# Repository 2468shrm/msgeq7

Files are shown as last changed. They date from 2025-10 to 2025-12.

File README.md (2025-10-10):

# msgeq7

A PCB to interface an MSGEQ7 seven channel graphic equalizer IC to my smart sensor platform [link](https://github.com/2468shrm/M4_CAN_Feather_Carrier_v6). The board has a microphone input jack, the MSGEQ7 IC, and three 3-position square pin headers. One header for RESET, one for STROBE, and one for the analog OUTPUT.  These are connected to two DIOs and an AIN, respectively.

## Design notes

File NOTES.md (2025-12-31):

# MSGEQ7 Project

## Requirements

- Audio input
  - Microphone input (3.5mm [1/8"] stereo jacks)
    - CUI SJ-3523-SMT (without switch)

- Connects to Smart Sensor Platform
  - 2 DIOs connect to STROBE and RESET and also provides 3.3V power
    - DIO power jumper
  - 1 AIN connects to DCOUT
- 3.3 V operation
  - 100 uF bulk cap
- MSGEQ7 PTH variant (from SparkFun)
  - Socketed

- Application on the mart Sensor Platform provides:
  - Bling output

- Sensor Platform
  - Battery powered

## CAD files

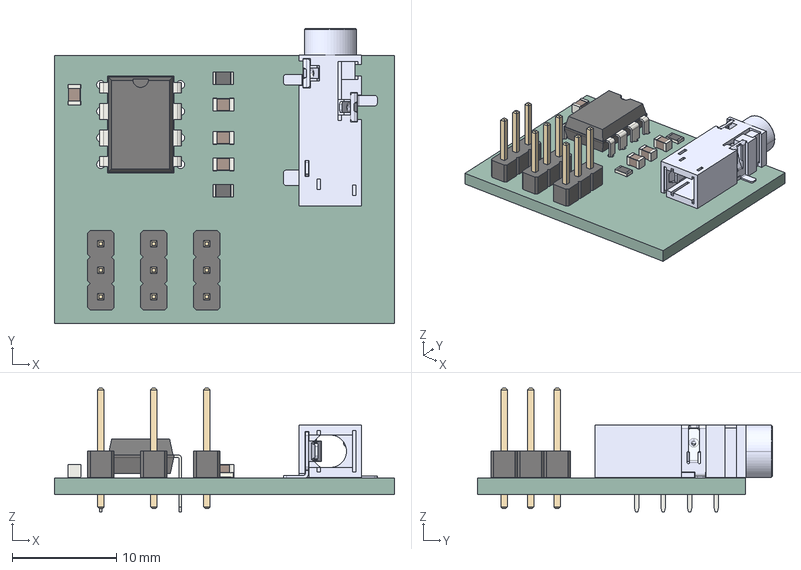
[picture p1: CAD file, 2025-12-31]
breakout/3D/breakout.step
32.6 x 28.2 x 11.8 mm
C_0805_2012Metric x 4
R_0805_2012Metric x 2
CUI_DEVICES_SJ-3523-SMT-TR
PinHeader_1x03_P254mm_Vertical x 3
DIP-8_W7.62mm
_autosave-breakout_PCB

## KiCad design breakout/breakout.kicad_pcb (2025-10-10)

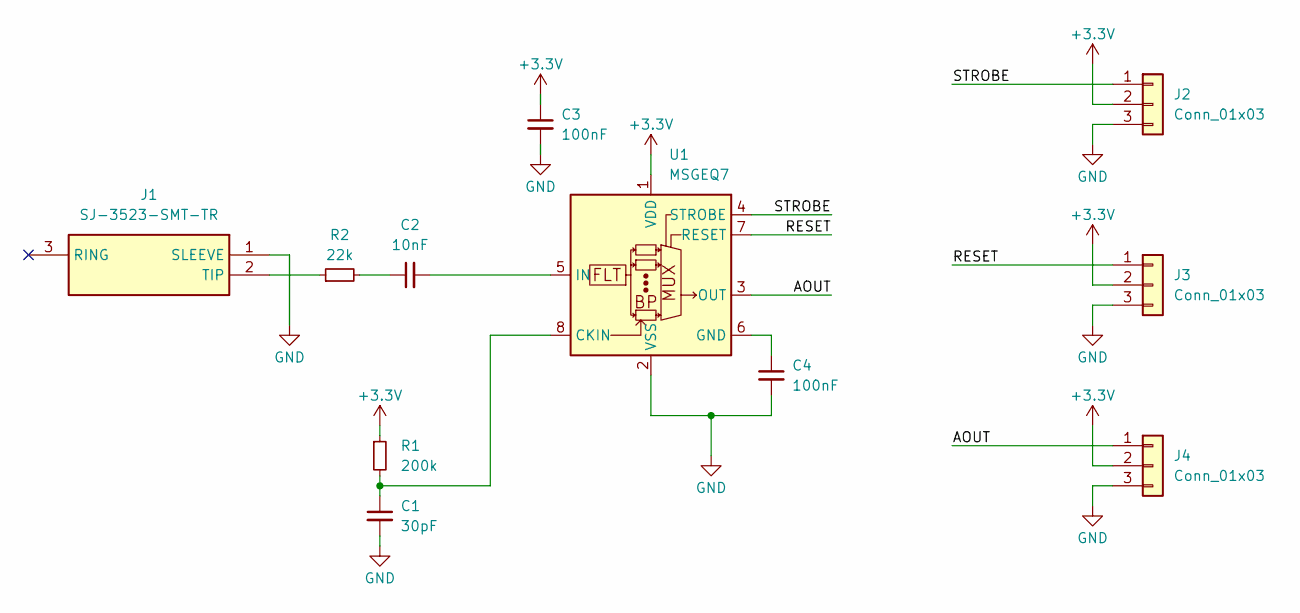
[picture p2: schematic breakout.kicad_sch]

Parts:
C1: 30pF; C_0805_2012Metric
C2: 10nF; C_0805_2012Metric
C3, C4: 100nF; C_0805_2012Metric
J1: SJ-3523-SMT-TR; SJ3523SMTTR; Manufacturer_Part_Number SJ-3523-SMT-TR; Mouser Part Number 490-SJ-3523-SMT-TR
J2, J3, J4: Conn_01x03; PinHeader_1x03_P2.54mm_Vertical
R1: 200k; R_0805_2012Metric
R2: 22k; R_0805_2012Metric
U1: MSGEQ7; DIP-8_W7.62mm_LongPads

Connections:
+3.3V: C3.1, J2.2, J3.2, J4.2, R1.1, U1.1 (VDD)
/AOUT: J4.1, U1.3 (OUT)
/RESET: J3.1, U1.7 (RESET)
/STROBE: J2.1, U1.4 (STROBE)
GND: C1.2, C3.2, C4.2, J1.1 (SLEEVE), J2.3, J3.3, J4.3, U1.2 (VSS)
unnamed: C2.1, R2.2
unnamed: J1.2 (TIP), R2.1
unnamed: C1.1, R1.2, U1.8 (CKIN)
unnamed: C4.1, U1.6 (GND)
unnamed: C2.2, U1.5 (IN)

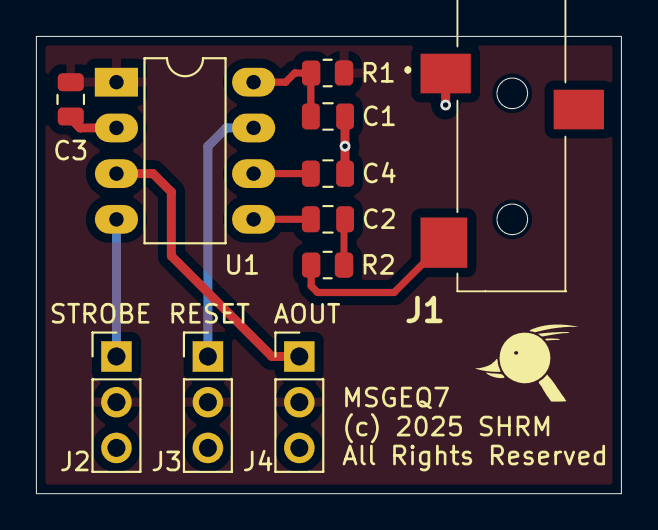
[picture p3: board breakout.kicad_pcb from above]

Board: 2 copper layers, 32.5 x 25.4 mm, 11 parts (0 on the bottom side), 10 nets.

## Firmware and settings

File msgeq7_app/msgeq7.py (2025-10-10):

import digitalio
import analogio
import time

class MSGEQ7:
    """
    Provides support for using an MSI MSGEQ7 seven band graphic equalizer
    IC.
    Product webpage
    https://www.mix-sig.com/index.php/msgeq7-seven-band-graphic-equalizer-display-filter
    Data sheet
    https://www.mix-sig.com/images/datasheets/MSGEQ7.pdf
    """
    # The index into the result list and sample sequence
    BAND_63Hz = 0
    BAND_160Hz = 1
    BAND_400Hz = 2
    BAND_1kHz = 3
    BAND_2_5kHz = 4
    BAND_6_25kHz = 5
    BAND_16kHz = 6

    # Times from the data sheet
    # RESET pulse width (high), min, µs -- 100 ns = 0.1 µs
    TIME_TR_NS = 100

    # RESET to STROBE delay, min, µs -- 72 us
    TIME_TRS_NS = 72000
    
    # STROBE pulse width, min, µs -- 20 µs
    TIME_TS_NS = 20000

    # STROBE to STROBE delay, min, µs -- 72 µs
    TIME_TSS_NS = 72000

    # OUTPUT settling time, min, µs -- 36 µs
    # The time from STROBE fall to initiating analog
    # sample
    TIME_TO_NS = 36000

    def delay(self, delay_ns: int):
        # Record the time on entry
        _now = time.monotonic_ns()
        while time.monotonic_ns() - _now < delay_ns:
            pass

    def __init__(self, pin_strobe:digitalio.DigitalInOut=None,
                 pin_reset:digitalio.DigitalInOut=None,
                 pin_output:analogio.AnalogIn=None) -> None:
        """
        An object for interfacing to a MSGEQ7 IC.
        Args:
            pin_strobe (digitalio.DigitalInOut): The MCU pin connected to
                the STROBE pin of the MSGEQ7
            pin_reset (digitalio.DigitalInOut): The MCU pin connected to
                the RESET pin of the MSGEQ7
            pin_output (analogio.AnalogIn): The MCU pin connected to
                the OUTPUT pin of the MSGEQ7
        """
        # Pin assignments and state construction
        self.pin_strobe = pin_strobe
        self.pin_reset = pin_reset
        self.pin_output= pin_output
        self.channel = [0] * 7

        # The constructor should also reset the MSGEQ7 IC's 
        # output multiplexer sequencer, by asserting and
        # de-asserting the RESET pin. Note the minimum times
        # per the MSGEQ7's datasheet
        self.pin_strobe.value = False
        self.pin_reset.value = False
        self.delay(self.TIME_TR_NS)

        self.pin_reset.value = True
        # Hold/assert time for a min of tr (or more)
        self.delay(self.TIME_TR_NS)
        # deassert (ready to start a new sequence)
        self.reset.value = False

        # Wait trs=72 us (min) before we can assert the first strobe
        self.delay(self.TIME_TRS_NS)

    def sample_sequence(self):
        """
        Generates the needed STROBE and sample sequence to read the
        peak power of each frequency band.
        """

        # Sample each channel in turn                
        for ch in range(0, 7):
            # assert strobe (high)
            self.strobe.value = True
            # Wait ts (or more)
            self.delay(self.TIME_TS_NS)
            # de-assert strobe (low)
            self.strobe.value = False

            # wait to sample and settle, to
            self.delay(self.TIME_TO_NS)
            # read the analog value on the OUT pin and save it
            self.channel[ch] = int (self.pin_output.value)

            # Wait for the next strobe (tss - to = 36 µs, or more)
            self.delay(self.TIME_TSS_NS - self.TIME_TO_NS)

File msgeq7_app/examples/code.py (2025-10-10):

import time
import array
from carrier_board.m4_feather_can import CarrierBoard
from adafruit_simplemath import map_range
# import board
# import neopixel
from msgeq7 import MSGEQ7

class EqDisplay:
    def __init__(self, num_pixels_per_band: int=0,
                 num_bands: int=0,
                 cb: CarrierBoard=None,
                 msgeq7: MSGEQ7=None) -> None:
        self.num_pixels = num_pixels_per_band
        self.num_bands = num_bands
        self.cb = cb
        self.msgeq7 = msgeq7
        self.last_channel = [0] * 7
    
    def update(self) -> None:
        _x = [map_range(chv, in_min=0, in_max=65535, out_min=0, 
                        out_max=self.num_pixels) for chv in self.msgeq7.channel]
        for ch in num_bands:
            for pi in range(self.num_pixels):
                cb.neopixel[pi] = (0,0,128) if _x[ch] > pi else ((0,0,16) if self.last_channel[ch] > pi else (0,0,0))
        cb.neopixel.show()
        self.last_channel = _x


#
# 
#
carrier_board_config = {
    "init_dio0": { "as_output": True},
    "init_dio1": { "as_output": True},
    "init_ain0": True,
    "init_neopixel": {
        "num_pixels": 7,
    },
}
cb = CarrierBoard(carrier_board_config)

msgeq7 = MSGEQ7(pin_reset=cb.dio0, pin_strobe=cb.dio1, pin_output=cb.ain0)

display = EqDisplay(num_pixels_per_band=7, cb=cb, msgeq7=msgeq7)

# msg.channel[i] is in range of 0-65535
# from simplemath import map_range
# new = map_range(value, in_min=0, in_max=65535, out_min=0, out_max=7)

while True:
    msgeq7.sample_sequence()
    for ch in range(0,7):
        cb.neopixel[ch] = intensity_to_color(msgeq7.channel[ch])
    cb.neopixel.show()

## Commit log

2025-10-10 KiCAD PCB files
    [breakout.kicad_pcb, breakout.kicad_sch]
2025-12-31 includes manufacturing and CAD files plus initial planning notes
    [breakout.step]

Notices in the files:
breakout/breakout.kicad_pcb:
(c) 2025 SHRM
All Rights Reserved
